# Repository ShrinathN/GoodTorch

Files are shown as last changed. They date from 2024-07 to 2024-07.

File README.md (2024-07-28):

# GoodTorch
An STM32G0 based torch for a 20W LED

# Summary
* STM32G0 MCU
* Boost converter (can operate in async or synchronous boost, depending on component placement)
* TP4056 based li-ion charging circuitry (1A max)
* USB-C for charging
* IR2104 gate driver (optional, if synchronous boost has to be used)

# Pics
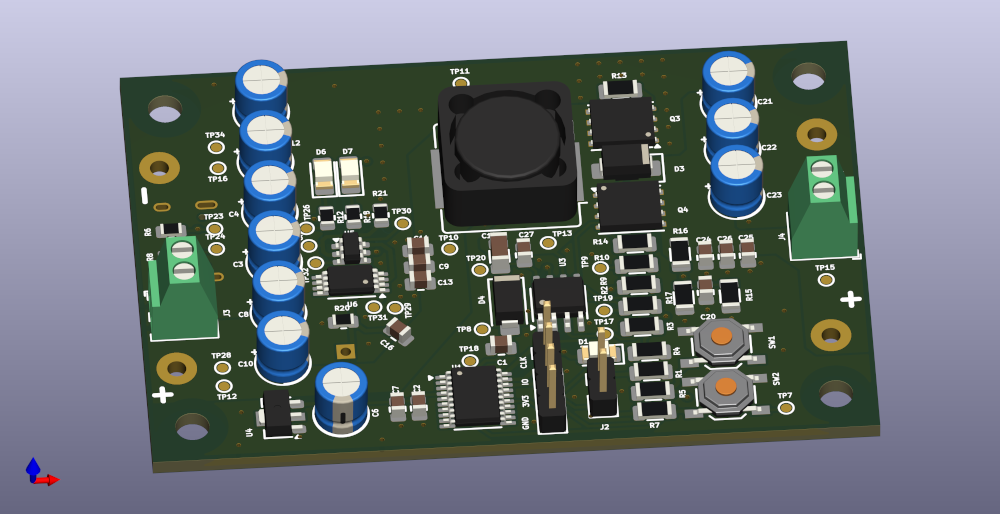
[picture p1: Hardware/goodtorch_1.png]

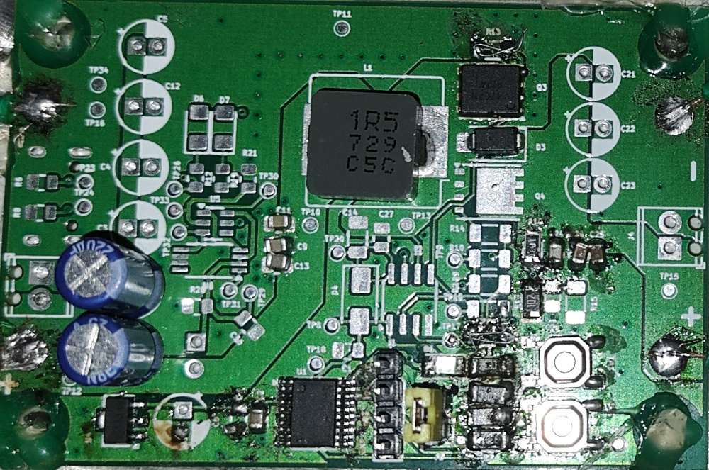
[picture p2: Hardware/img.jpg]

PCB

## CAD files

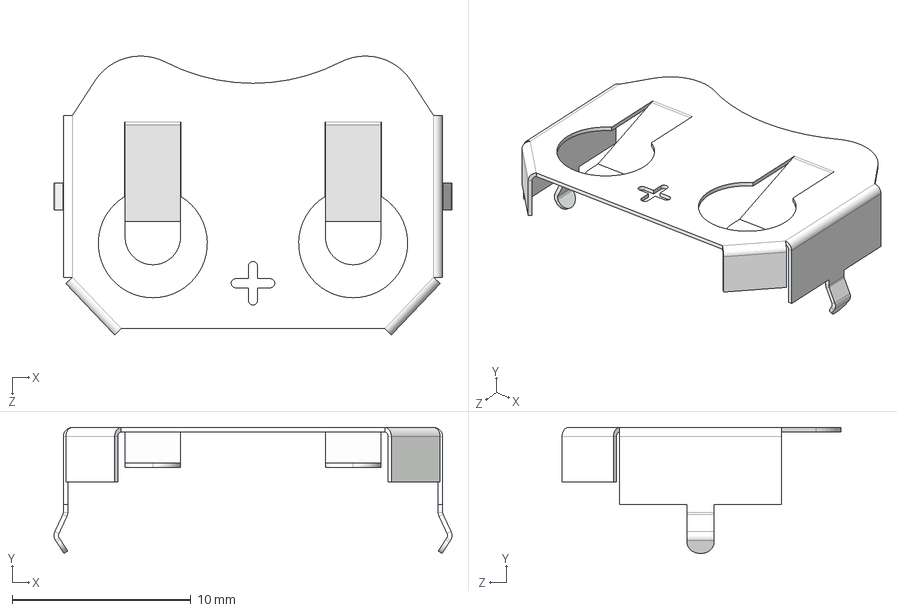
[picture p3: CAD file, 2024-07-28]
Hardware/goodtorch/Custom Parts/3D Models/keystone-PN3035.STEP
22.2 x 7.04 x 15.6 mm

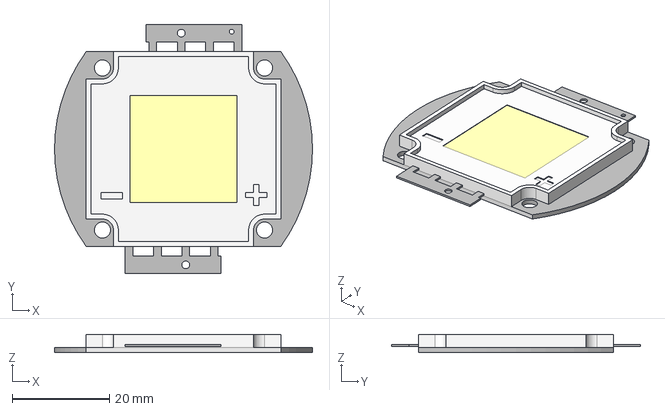
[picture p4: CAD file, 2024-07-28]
Hardware/goodtorch/design_documents/cob_led_20w-PartPocket003.step
53.0 x 51.2 x 3.70 mm

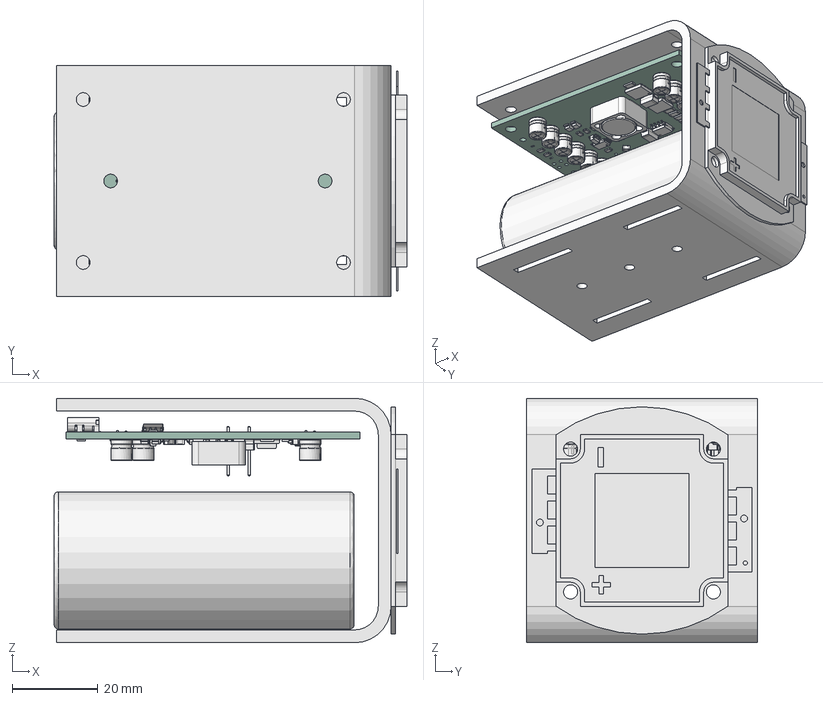
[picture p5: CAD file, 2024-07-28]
Hardware/goodtorch/Enclosure/goodtorch_enclosure.FCStd
82.3 x 53.8 x 57.0 mm
SW_SPST_TL3342
CP_Radial_D50mm_P200mm
R_1206_3216Metric
C_0805_2012Metric
R_1206_3216Metric002
C_0805_2012Metric002
TSSOP_20_44x65mm_P065mm
CP_Radial_D50mm_P200mm001
R_1206_3216Metric004
R_0805_2012Metric
C_1206_3216Metric
R_0805_2012Metric002
D_SMA
R_1206_3216Metric006
R_1206_3216Metric008
TDSON_8_1
CP_Radial_D50mm_P200mm002
CQ assembly
CQ assembly001
CQ assembly002
CQ assembly003
CQ assembly004
C_0805_2012Metric004
R_1206_3216Metric010
R_1206_3216Metric012
R_0805_2012Metric004
TSSOP_8_44x3mm_P065mm
R_1206_3216Metric014
C_0805_2012Metric006
R_0805_2012Metric006
CP_Radial_D50mm_P200mm003
C_0805_2012Metric008
CP_Radial_D50mm_P200mm004
R_1206_3216Metric016
R_0805_2012Metric008
C_0805_2012Metric010
PinHeader_1x02_P254mm_Vertical
PinHeader_1x04_P254mm_Vertical
C_0805_2012Metric012
C_0805_2012Metric014
CP_Radial_D50mm_P200mm005
LED_1206_3216Metric
SRR1260
R_1206_3216Metric018
SW_SPST_TL3344
C_0805_2012Metric016
R_1206_3216Metric020
CP_Radial_D50mm_P200mm006
CP_Radial_D50mm_P200mm007
R_1206_3216Metric022
LED_1206_3216Metric002
SOIC_8_39x49mm_P127mm
SOT_23_6
TDSON_8_002
C_0805_2012Metric018
C_0805_2012Metric020
CP_Radial_D50mm_P200mm008
R_0805_2012Metric010
CP_Radial_D50mm_P200mm009
C_0805_2012Metric022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

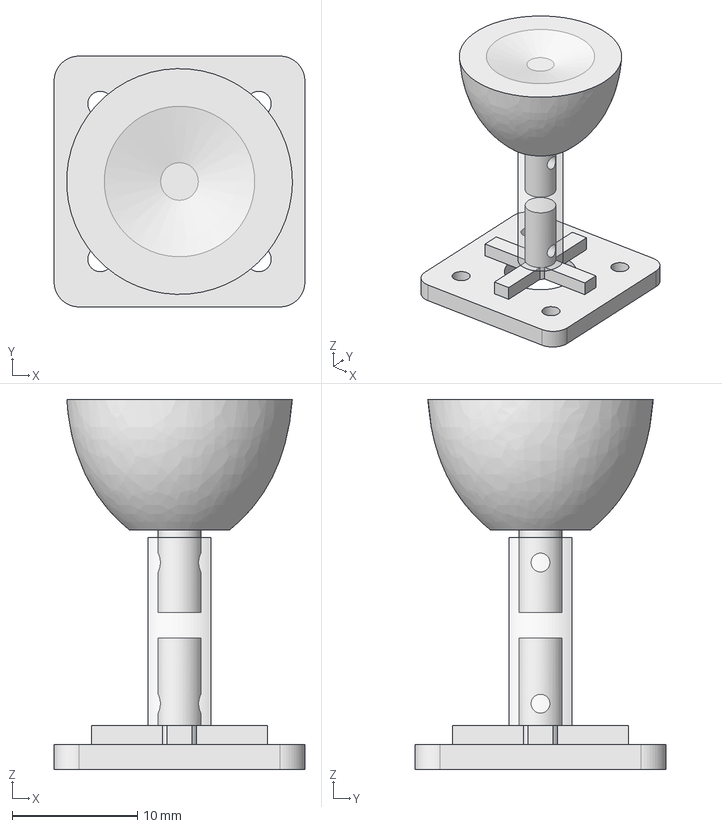
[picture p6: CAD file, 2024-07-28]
Hardware/goodtorch/Custom Parts/3D Models/heheboy.step
20.0 x 20.0 x 29.5 mm
Deflector_Body
Spring_Body

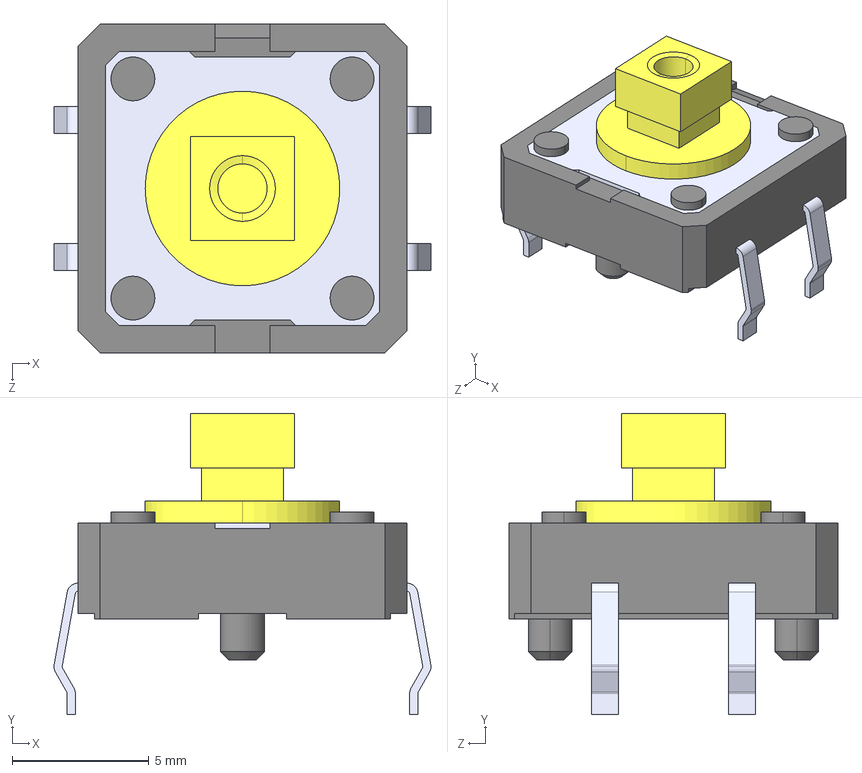
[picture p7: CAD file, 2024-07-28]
Hardware/goodtorch/Custom Parts/3D Models/B3F-4055--3DModel-STEP-418109.STEP
13.8 x 11.0 x 12.0 mm

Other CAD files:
Hardware/goodtorch/design_documents/cob_led_20w.FCStd

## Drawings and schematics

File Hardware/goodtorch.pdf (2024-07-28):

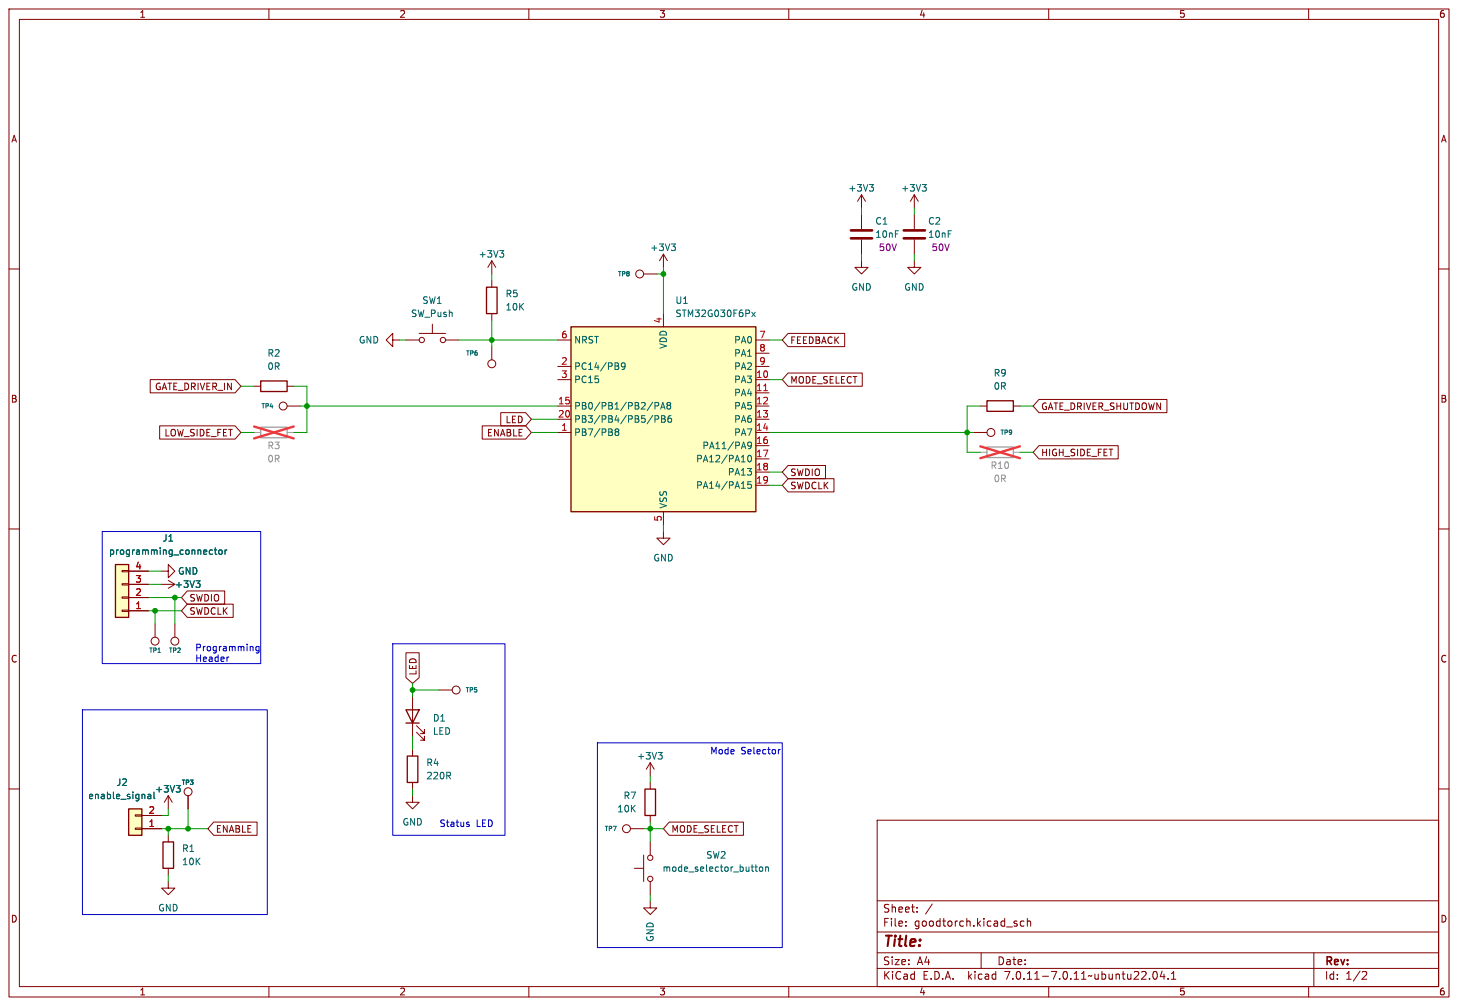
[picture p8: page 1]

Id: 1/2 Title: File: goodtorch.kicad_sch Sheet: /

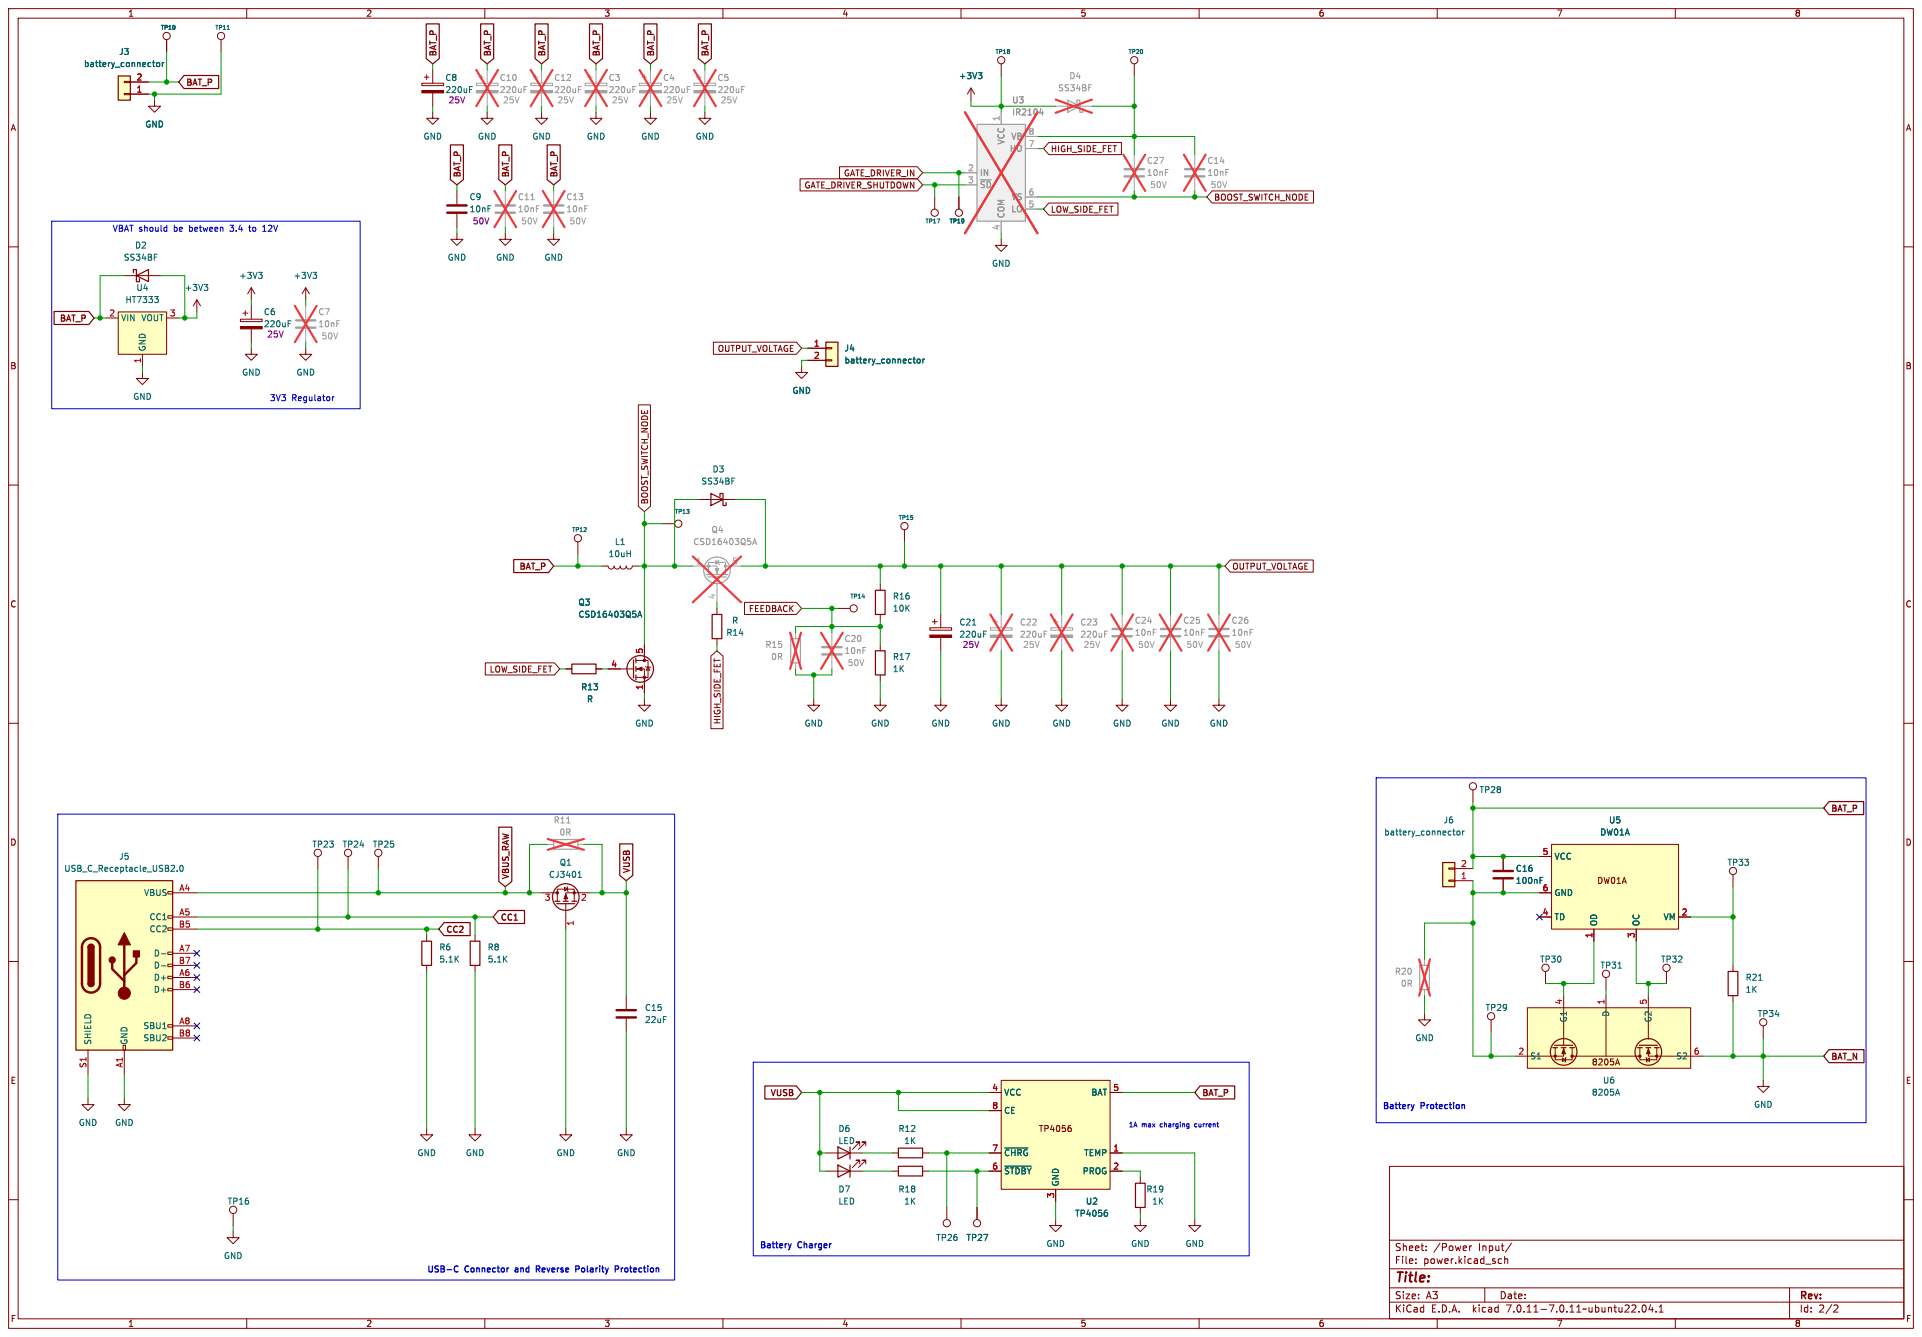
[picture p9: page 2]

1 VIN 2 VOUT 3 U4 HT7333 +3V3 GND GND

3V3 Regulator VBAT should be between 3.4 to 12V

3 VCC 4 BAT 5 ~{STDBY} 6 ~{CHRG} 7 CE 8 U2 TP4056 GND TP27 D7

3 VCC 4 BAT 5 ~{STDBY} 6 ~{CHRG} 7 CE 8 TP27

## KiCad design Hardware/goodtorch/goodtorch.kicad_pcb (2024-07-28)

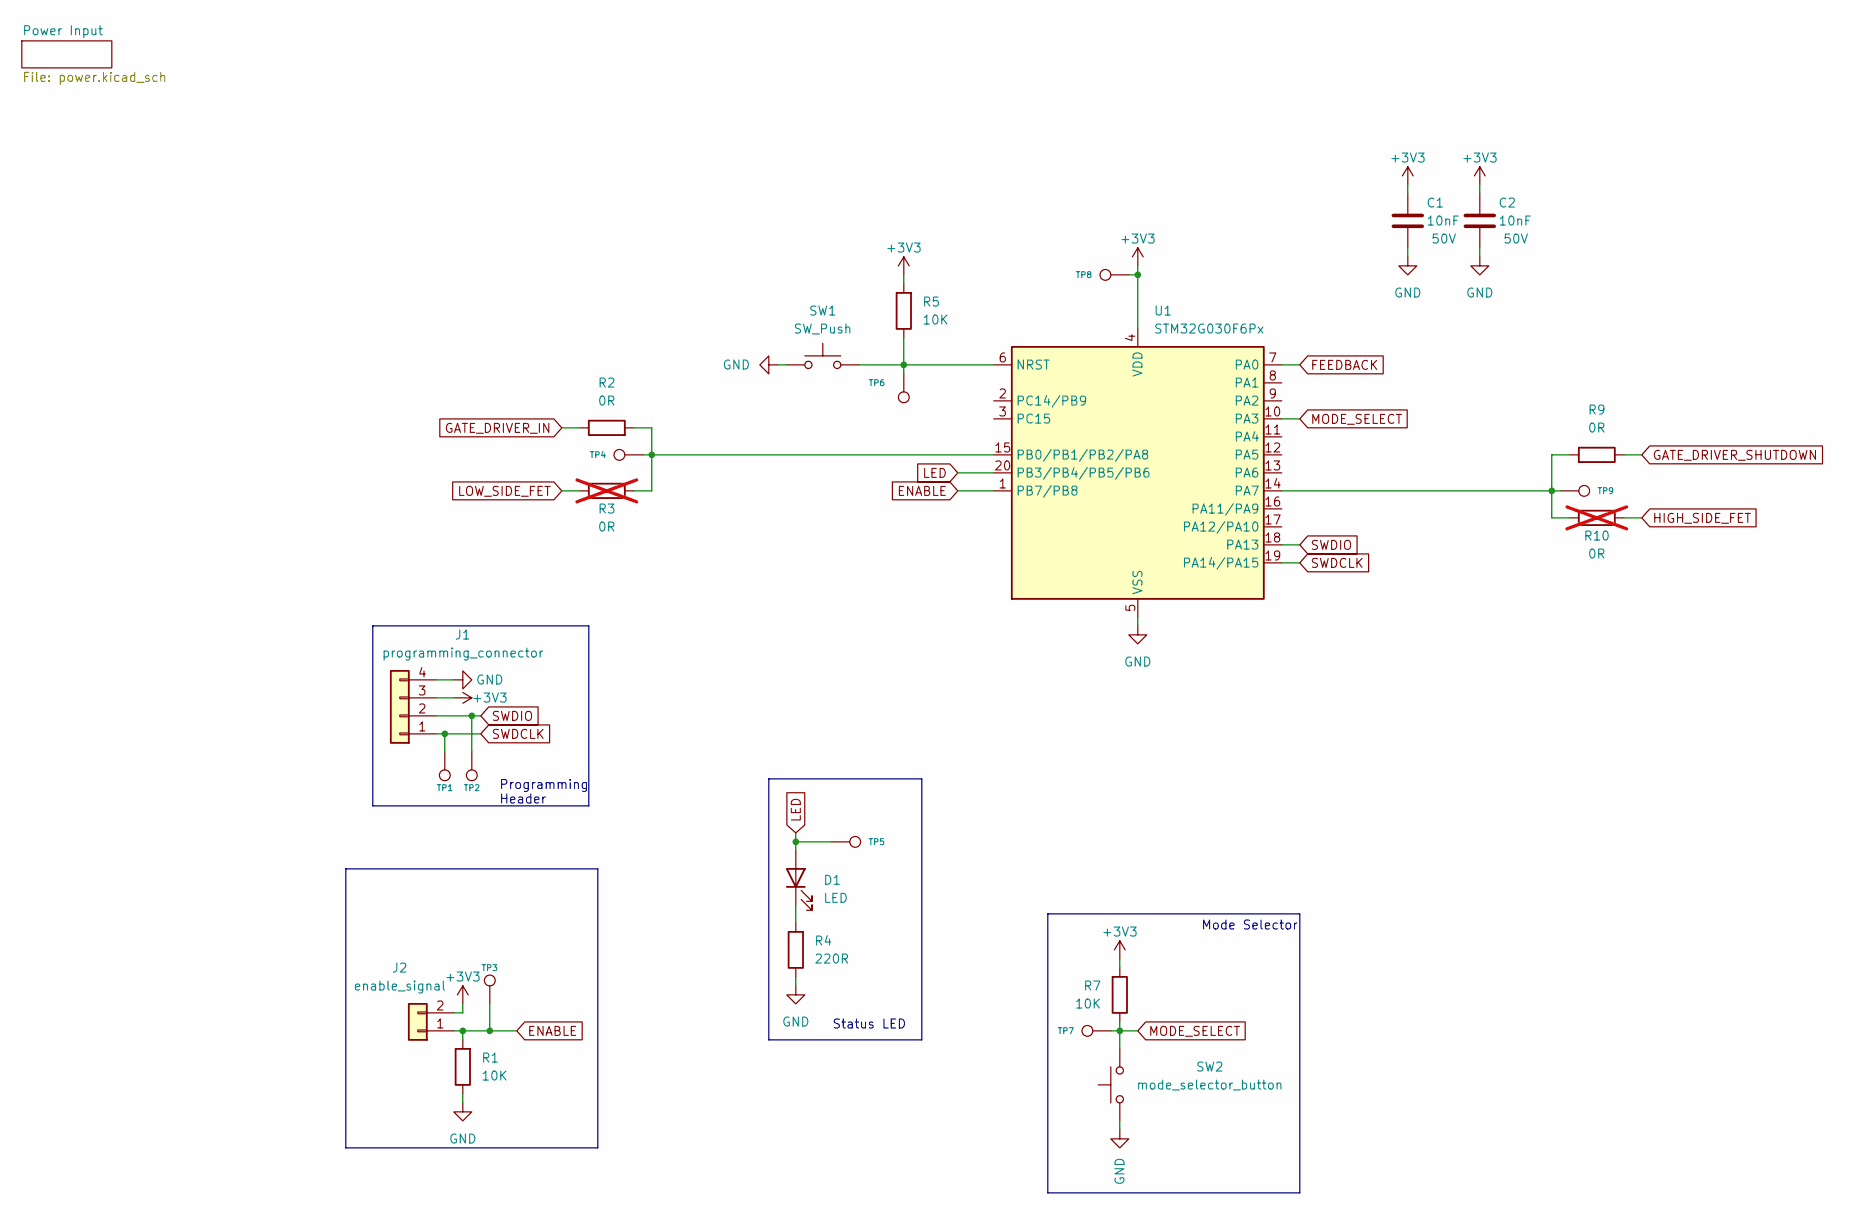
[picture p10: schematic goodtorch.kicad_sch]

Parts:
C1, C2: 10nF; C_0805_2012Metric; Rating 50V
D1: LED; LED_1206_3216Metric
J1: programming_connector; PinHeader_1x04_P2.54mm_Vertical
J2: enable_signal; PinHeader_1x02_P2.54mm_Vertical
R1, R5, R7: 10K; R_1206_3216Metric
R2, R9: 0R; R_1206_3216Metric
R3, R10: 0R; R_1206_3216Metric; not fitted
R4: 220R; R_1206_3216Metric
SW1: SW_Push; SW_SPST_TL3342
SW2: mode_selector_button; SW_SPST_TL3342
TP1, TP2, TP3, TP4, TP5, TP6, TP7, TP8, TP9: TestPoint; TestPoint_Pad_D1.0mm
U1: STM32G030F6Px; TSSOP-20_4.4x6.5mm_P0.65mm

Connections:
+3V3: C1.1, C2.1, J1.3, J2.2, R5.2, R7.2, TP8.1, U1.4 (VDD); also elsewhere on the board
BAT_N: C1.2, C2.2, J1.4, R1.1, R4.1, SW1.1, SW2.1, U1.5 (VSS); also elsewhere on the board
ENABLE: J2.1, R1.2, TP3.1, U1.1 (PB7/PB8)
FEEDBACK: U1.7 (PA0); also elsewhere on the board
GATE_DRIVER_IN: R2.1; also elsewhere on the board
GATE_DRIVER_SHUTDOWN: R9.1; also elsewhere on the board
HIGH_SIDE_FET: R10.1; also elsewhere on the board
LED: D1.2 (A), TP5.1, U1.20 (PB3/PB4/PB5/PB6)
LOW_SIDE_FET: R3.1; also elsewhere on the board
MODE_SELECT: R7.1, SW2.2, TP7.1, U1.10 (PA3)
unnamed: D1.1 (K), R4.2
unnamed: R5.1, SW1.2, TP6.1, U1.6 (NRST)
unnamed: R9.2, R10.2, TP9.1, U1.14 (PA7)
unnamed: R2.2, R3.2, TP4.1, U1.15 (PB0/PB1/PB2/PA8)
SWDCLK: J1.1, TP1.1, U1.19 (PA14/PA15)
SWDIO: J1.2, TP2.1, U1.18 (PA13)

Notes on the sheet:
Status LED
Programming Header
Mode Selector

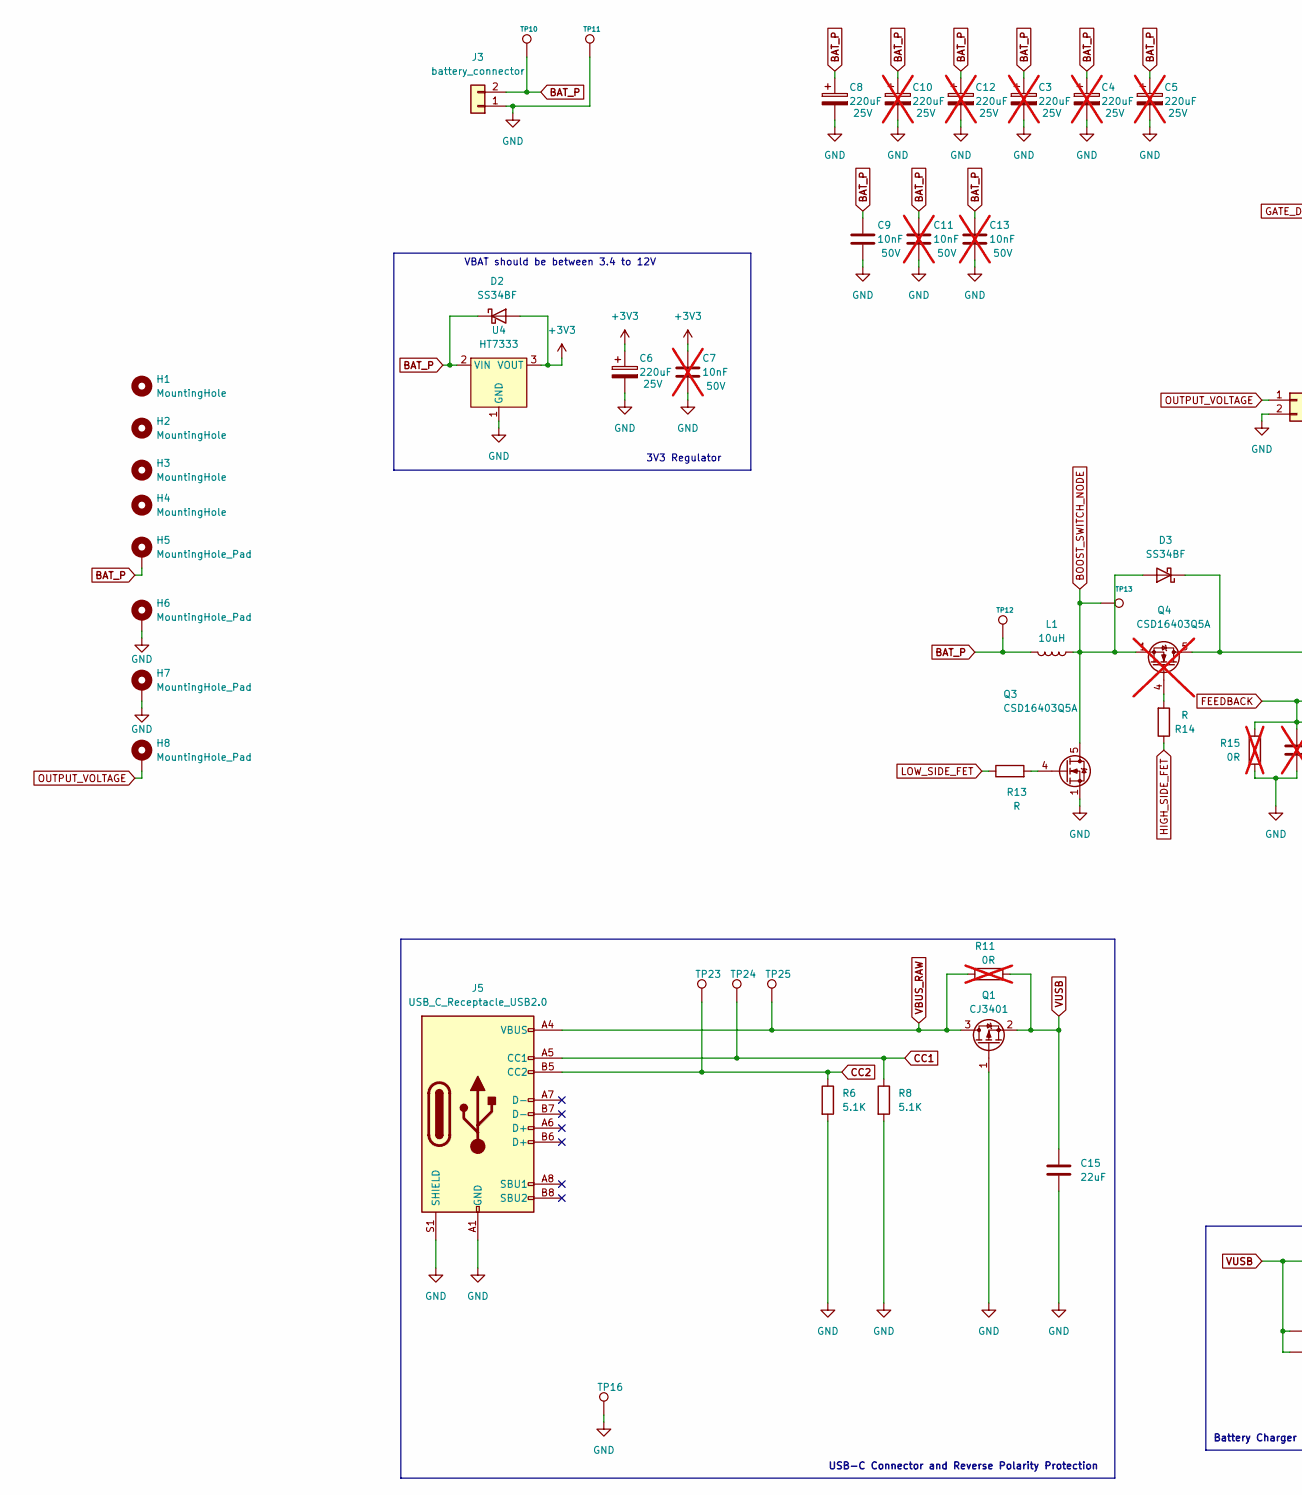
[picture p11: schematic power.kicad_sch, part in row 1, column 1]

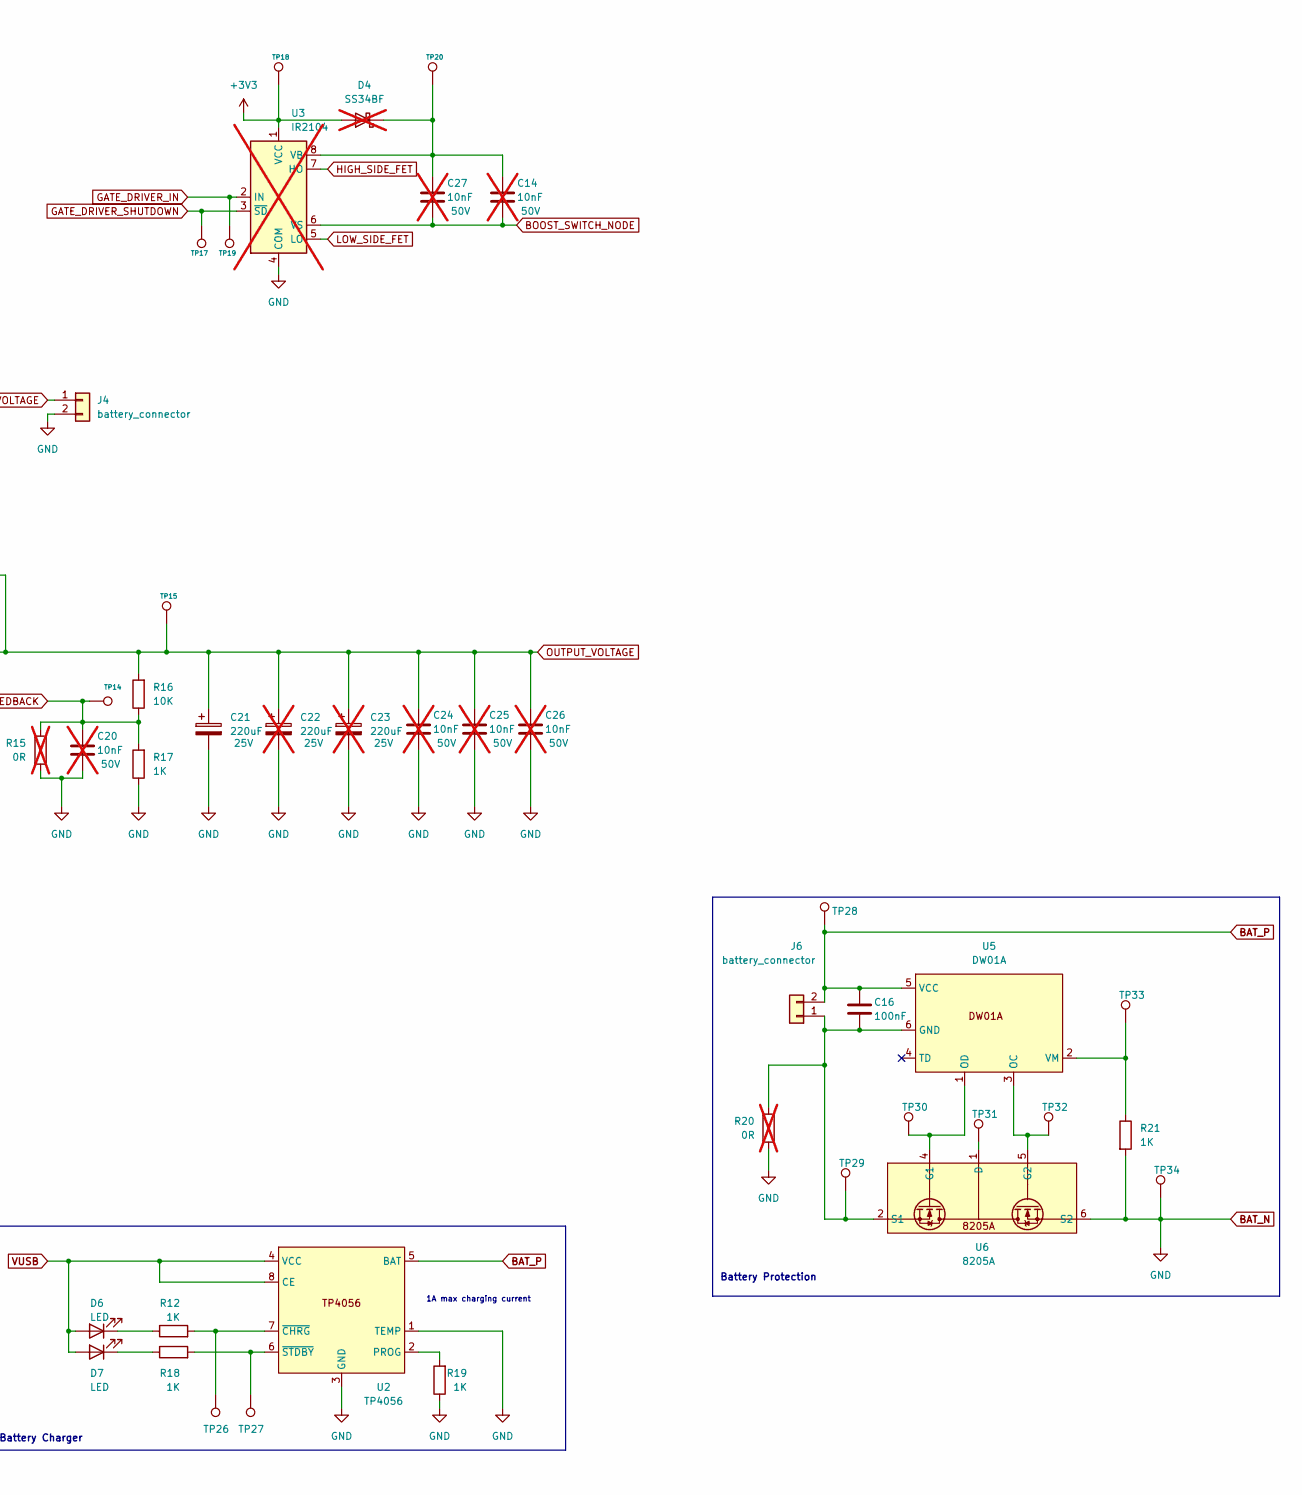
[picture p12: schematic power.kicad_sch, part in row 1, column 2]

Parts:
C3, C4, C5, C10, C12, C22, C23: 220uF; CP_Radial_D5.0mm_P2.00mm; Rating 25V; not fitted
C6, C8, C21: 220uF; CP_Radial_D5.0mm_P2.00mm; Rating 25V
C7, C11, C13, C20, C24, C25, C26, C27: 10nF; C_0805_2012Metric; Rating 50V; not fitted
C9: 10nF; C_0805_2012Metric; Rating 50V
C14: 10nF; C_1206_3216Metric; Rating 50V; not fitted
C15: 22uF; C_0805_2012Metric
C16: 100nF; C_0805_2012Metric
D2, D3: SS34BF; D_SMA; Rating 40V 3A
D4: SS34BF; D_SMA; Rating 40V 3A; not fitted
D6, D7: LED; LED_1206_3216Metric_Pad1.42x1.75mm_HandSolder
H1, H2, H3, H4: MountingHole; MountingHole_3.2mm_M3
H5, H6, H7, H8: MountingHole_Pad; MountingHole_2.2mm_M2_DIN965_Pad
J3, J4: battery_connector; TerminalBlock_Phoenix_MPT-0,5-2-2.54_1x02_P2.54mm_Horizontal
J5: USB_C_Receptacle_USB2.0; USB_C_Receptacle_XKB_U262-16XN-4BVC11
J6: battery_connector; PinHeader_1x02_P2.54mm_Horizontal
L1: 10uH; L_Bourns_SRR1208_12.7x12.7mm
Q1: CJ3401; SOT-23
Q3: CSD16403Q5A; TDSON-8-1
Q4: CSD16403Q5A; TDSON-8-1; not fitted
R6, R8: 5.1K; R_0805_2012Metric
R11, R20: 0R; R_0805_2012Metric; not fitted
R12, R18, R19, R21: 1K; R_0805_2012Metric
R13, R14: R; R_1206_3216Metric
R15: 0R; R_1206_3216Metric; not fitted
R16: 10K; R_1206_3216Metric
R17: 1K; R_1206_3216Metric
TP10, TP11, TP12, TP13, TP14, TP15, TP16, TP17, TP18, TP19, TP20, TP23, TP24, TP25, TP26, TP27, TP28, TP29, TP30, TP31, TP32, TP33, TP34: TestPoint; TestPoint_Pad_D1.0mm
U2: TP4056; SOP-8_3.9x4.9mm_P1.27mm
U3: IR2104; SOIC-8_3.9x4.9mm_P1.27mm; not fitted
U4: HT7333; SOT-89-3
U5: DW01A; SOT-23-6
U6: 8205A; TSSOP-8_4.4x3mm_P0.65mm

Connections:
+3V3: C6.1, C7.1, D2.2 (A), D4.2 (A), TP18.1, U3.1 (VCC), U4.3 (VOUT); also elsewhere on the board
BAT_N: C3.2, C4.2, C5.2, C6.2, C7.2, C8.2, C9.2, C10.2, C11.2, C12.2, C13.2, C15.2, C20.2, C21.2, C22.2, C23.2, C24.2, C25.2, C26.2, H6.1, H7.1, J3.1, J4.2, J5.A1 (GND), J5.A12 (GND), J5.B1 (GND), J5.B12 (GND), J5.S1 (SHIELD), Q1.1 (G), Q3.1 (S), Q3.2 (S), Q3.3 (S), R6.2, R8.2, R15.2, R17.1, R19.1, R20.1, R21.2, TP11.1, TP16.1, TP34.1, U2.1 (TEMP), U2.3 (GND), U3.4 (COM), U4.1 (GND), U6.6 (S2), U6.7 (S2); also elsewhere on the board
BAT_P: C3.1, C4.1, C5.1, C8.1, C9.1, C10.1, C11.1, C12.1, C13.1, C16.1, D2.1 (K), H5.1, J3.2, J6.2, L1.2, TP10.1, TP12.1, TP28.1, U2.5 (BAT), U4.2 (VIN), U5.5 (VCC)
BOOST_SWITCH_NODE: C14.2, C27.2, D3.2 (A), L1.1, Q3.5 (D), Q4.1 (S), Q4.2 (S), Q4.3 (S), TP13.1, U3.6 (VS)
CC1: J5.A5 (CC1), R8.1, TP24.1
CC2: J5.B5 (CC2), R6.1, TP23.1
FEEDBACK: C20.1, R15.1, R16.1, R17.2, TP14.1; also elsewhere on the board
GATE_DRIVER_IN: TP19.1, U3.2 (IN); also elsewhere on the board
GATE_DRIVER_SHUTDOWN: TP17.1, U3.3 (~SD); also elsewhere on the board
HIGH_SIDE_FET: R14.1, U3.7 (HO); also elsewhere on the board
LOW_SIDE_FET: R13.1, U3.5 (LO); also elsewhere on the board
unnamed: C14.1, C27.1, D4.1 (K), TP20.1, U3.8 (VB)
unnamed: D6.1 (K), R12.1
unnamed: D7.1 (K), R18.1
unnamed: C16.2, J6.1, R20.2, TP29.1, U5.6 (GND), U6.2 (S1), U6.3 (S1)
unnamed: Q3.4 (G), R13.2
unnamed: Q4.4 (G), R14.2
unnamed: TP31.1, U6.1 (D), U6.8 (D)
unnamed: R19.2, U2.2 (PROG)
unnamed: R12.2, TP26.1, U2.7 (~CHRG)
unnamed: R18.2, TP27.1, U2.6 (~STDBY)
unnamed: TP32.1, U5.3 (OC), U6.5 (G2)
unnamed: TP30.1, U5.1 (OD), U6.4 (G1)
unnamed: R21.1, TP33.1, U5.2 (VM)
OUTPUT_VOLTAGE: C21.1, C22.1, C23.1, C24.1, C25.1, C26.1, D3.1 (K), H8.1, J4.1, Q4.5 (D), R16.2, TP15.1
VBUS_RAW: J5.A4 (VBUS), J5.A9 (VBUS), J5.B4 (VBUS), J5.B9 (VBUS), Q1.3 (D), R11.1, TP25.1
VUSB: C15.1, D6.2 (A), D7.2 (A), Q1.2 (S), R11.2, U2.4 (VCC), U2.8 (CE)

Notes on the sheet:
Battery Protection
VBAT should be between 3.4 to 12V
3V3 Regulator
1A max charging current
USB-C Connector and Reverse Polarity Protection
Battery Charger

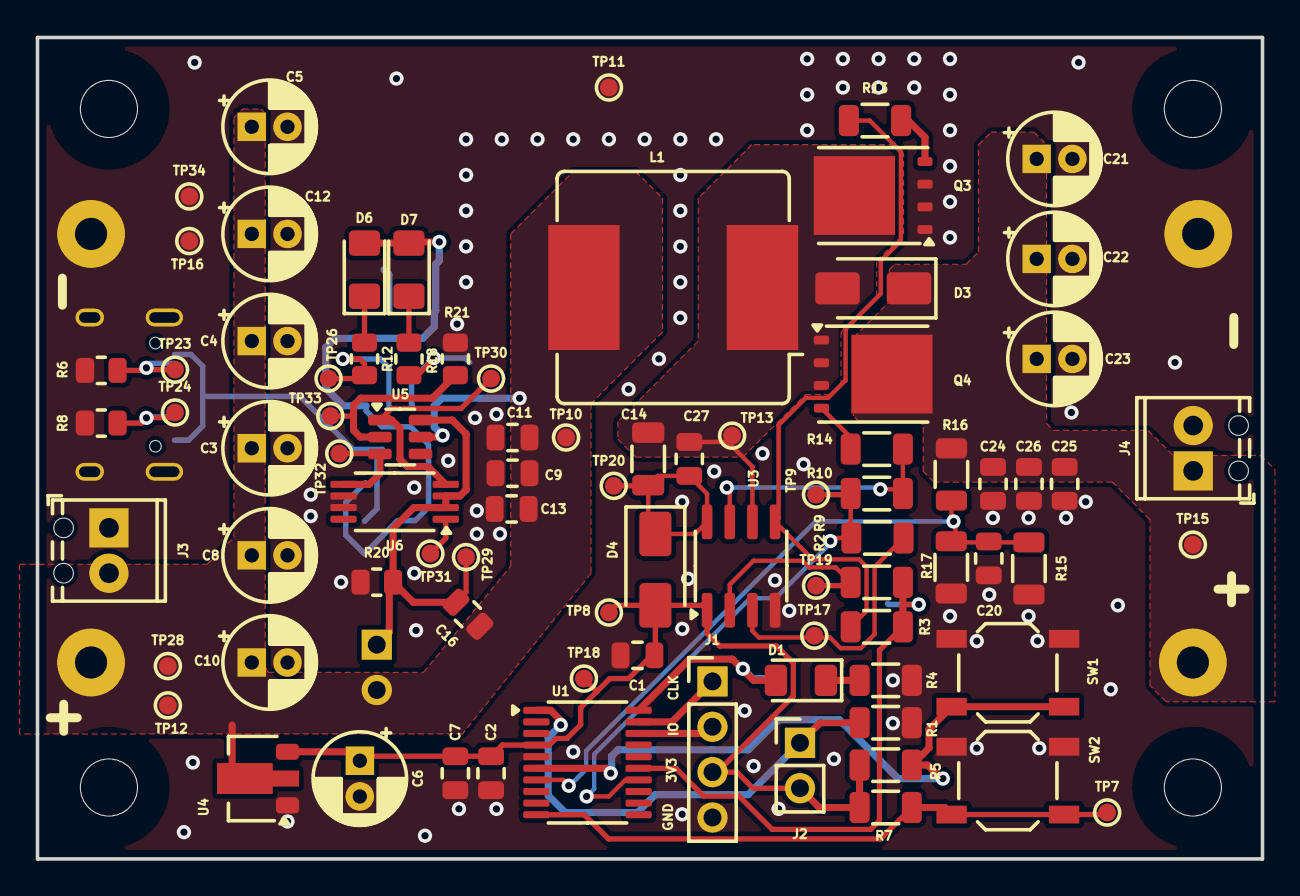
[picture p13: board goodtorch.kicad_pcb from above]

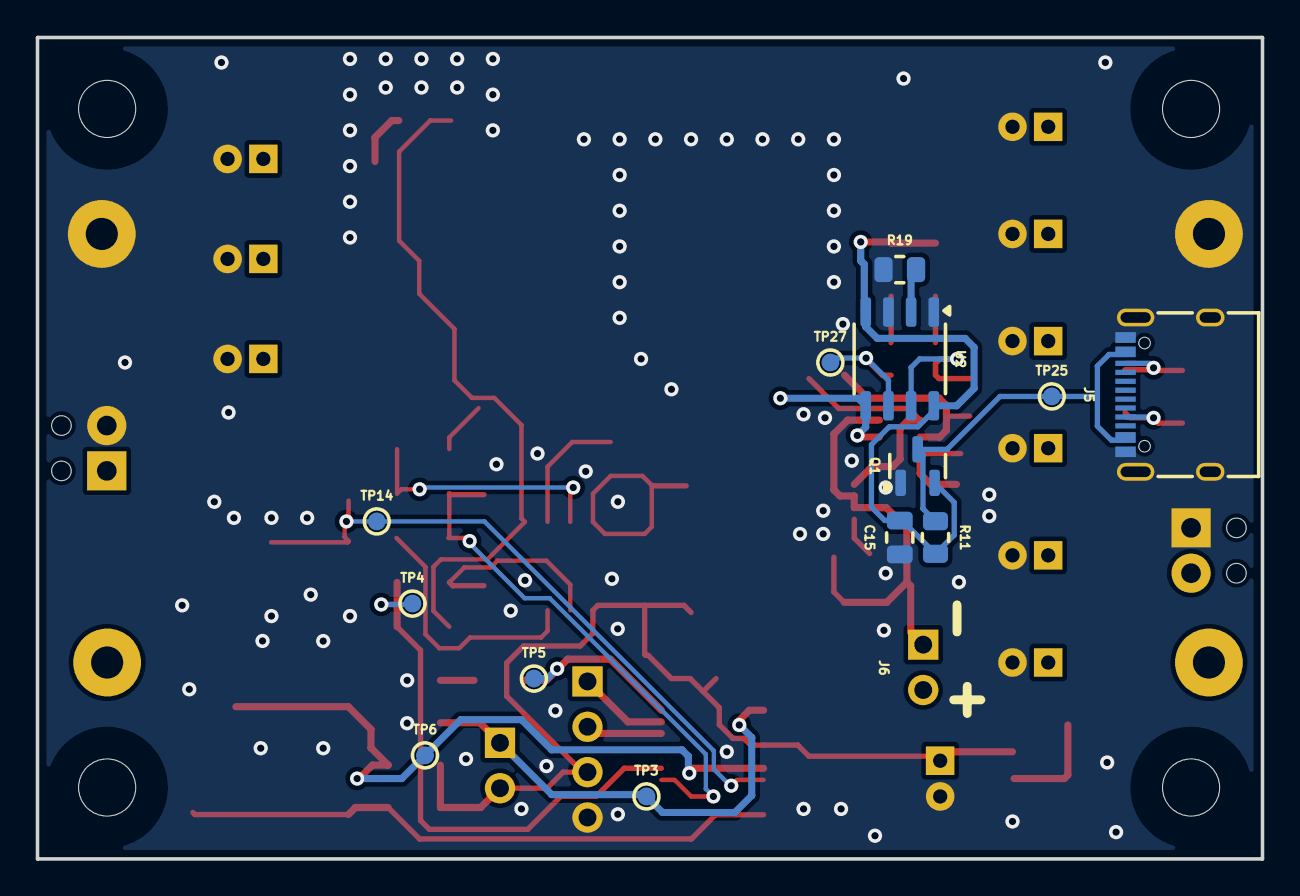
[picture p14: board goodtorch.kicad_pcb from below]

Board: 2 copper layers, 68.6 x 46.0 mm, 106 parts (14 on the bottom side), 36 nets.

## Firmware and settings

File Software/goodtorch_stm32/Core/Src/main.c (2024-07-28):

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
/* Includes ------------------------------------------------------------------*/
#include "main.h"

ADC_HandleTypeDef hadc1;

TIM_HandleTypeDef htim1;

void SystemClock_Config(void);
static void MX_GPIO_Init(void);
static void MX_TIM1_Init(void);
static void MX_ADC1_Init(void);
/* USER CODE BEGIN 0 */
uint8_t get_mode_button()
{
  return HAL_GPIO_ReadPin(MODE_SELECT_GPIO_Port, MODE_SELECT_Pin);
}
/* USER CODE END 0 */

/**
 * @brief  The application entry point.
 * @retval int
 */
int main(void)
{
  /* MCU Configuration--------------------------------------------------------*/

  /* Reset of all peripherals, Initializes the Flash interface and the Systick. */
  HAL_Init();

  /* Configure the system clock */
  SystemClock_Config();

  /* Initialize all configured peripherals */
  MX_GPIO_Init();
  MX_TIM1_Init();
  MX_ADC1_Init();
  /* Infinite loop */
  /* USER CODE BEGIN WHILE */

  // deiniting the timer by default
  // HAL_TIM_Base_MspDeInit(&htim1);

  // this will be low if the jumper is not placed
  // when its low, we don't want to run anything
  if (HAL_GPIO_ReadPin(ENABLE_GPIO_Port, ENABLE_Pin) == 0)
  {
    while (1)
    {
      HAL_GPIO_TogglePin(LED_GPIO_Port, LED_Pin);
      HAL_Delay(100);
      HAL_GPIO_TogglePin(LED_GPIO_Port, LED_Pin);
      HAL_Delay(100);
    }
  }

  // if everything is fine
  uint8_t mode_change = 1;
  uint8_t mode = 0;
  uint8_t mode_ctr = 0;
  HAL_TIM_PWM_Start(&htim1, TIM_CHANNEL_1);

  while (1)
  {
    // if its low
    if (get_mode_button() == 0)
    {
      // we wait it to become high again (released)
      while (get_mode_button() == 0)
      {
      };
      mode_change = 1;
      mode_ctr++;
      mode = mode_ctr % 5;
      HAL_Delay(100);
    }

    // selecting the mode
    if (mode_change)
    {
      mode_change = 0;

      // select the appropriate mode
      if (mode == 0) // this is off
      {
        __HAL_TIM_SET_COMPARE(&htim1, TIM_CHANNEL_1, 0); // 0% duty cycle
        // HAL_PWR_EnterSTANDBYMode();
      }

      if (mode == 1)
      {
        __HAL_TIM_SET_COMPARE(&htim1, TIM_CHANNEL_1, 10); // 10% duty cycle
      }

      else if (mode == 2)
      {
        // HAL_TIM_PWM_Start(&htim1, TIM_CHANNEL_1);
        // HAL_TIM_MspPostInit(&htim1);
        __HAL_TIM_SET_COMPARE(&htim1, TIM_CHANNEL_1, 16); // 25% duty cycle
      }

      else if (mode == 3)
      {
        // HAL_TIM_PWM_Start(&htim1, TIM_CHANNEL_1);
        // HAL_TIM_MspPostInit(&htim1);
        __HAL_TIM_SET_COMPARE(&htim1, TIM_CHANNEL_1, 32); // 50% duty cycle
      }

      else if (mode == 4)
      {
        // HAL_TIM_PWM_Start(&htim1, TIM_CHANNEL_1);
        // HAL_TIM_MspPostInit(&htim1);
        __HAL_TIM_SET_COMPARE(&htim1, TIM_CHANNEL_1, 45); // 70% duty cycle
      }
    }
    /* USER CODE END WHILE */

    /* USER CODE BEGIN 3 */
  }
  /* USER CODE END 3 */
}

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


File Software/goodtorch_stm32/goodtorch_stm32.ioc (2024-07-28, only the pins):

Mcu.UserName=STM32G030F6Px
PA0.Signal=ADC1_IN0
PA13.Signal=SYS_SWDIO
PA14-BOOT0.Signal=SYS_SWCLK
PA3.GPIO_Label=MODE_SELECT
PA3.Signal=GPXTI3
PA8.Signal=S_TIM1_CH1
PB3.GPIO_Label=LED
PB3.Signal=GPIO_Output
PB7.GPIO_Label=ENABLE
PB7.Signal=GPIO_Input

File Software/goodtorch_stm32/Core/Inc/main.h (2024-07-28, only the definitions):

#define ENABLE_Pin GPIO_PIN_7
#define ENABLE_GPIO_Port GPIOB
#define MODE_SELECT_Pin GPIO_PIN_3
#define MODE_SELECT_GPIO_Port GPIOA
#define MODE_SELECT_EXTI_IRQn EXTI2_3_IRQn
#define LED_Pin GPIO_PIN_3
#define LED_GPIO_Port GPIOB

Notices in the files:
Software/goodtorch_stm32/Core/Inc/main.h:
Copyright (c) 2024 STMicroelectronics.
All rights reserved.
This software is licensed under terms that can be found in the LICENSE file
